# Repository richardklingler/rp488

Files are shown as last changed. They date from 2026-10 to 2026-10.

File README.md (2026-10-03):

# RP488 USB-GPIB Adapter

This project is an RP2350-based USB GPIB adapter.

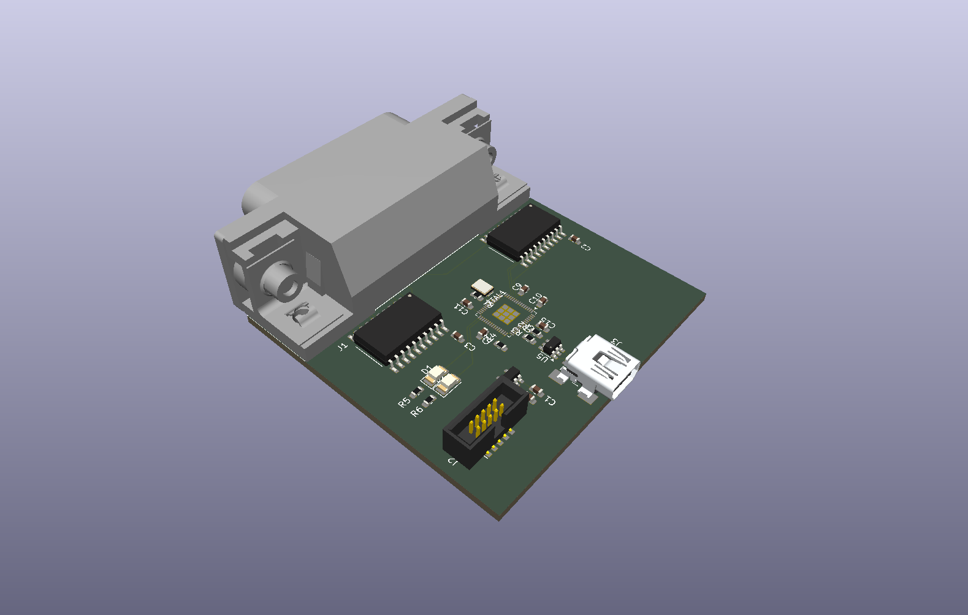
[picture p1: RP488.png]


## USB identifiers

- Vendor ID: `0x1209`
- Product ID: `0x5305`

## Hardware target

- Raspberry Pi Pico 2 W, RP2354
- SN75160B data transceiver
- SN75161B control transceiver
- GPIB bus interface using negative-true logic

## Test

The design was tested with a Raspberry Pi Pico 2 W board and an attached Yokogawa DL1540C 4-channel scope.
I was able to control the scope and download a binary screenshot as TIFF on macOS 27 with a simple Python script located in folder "test".

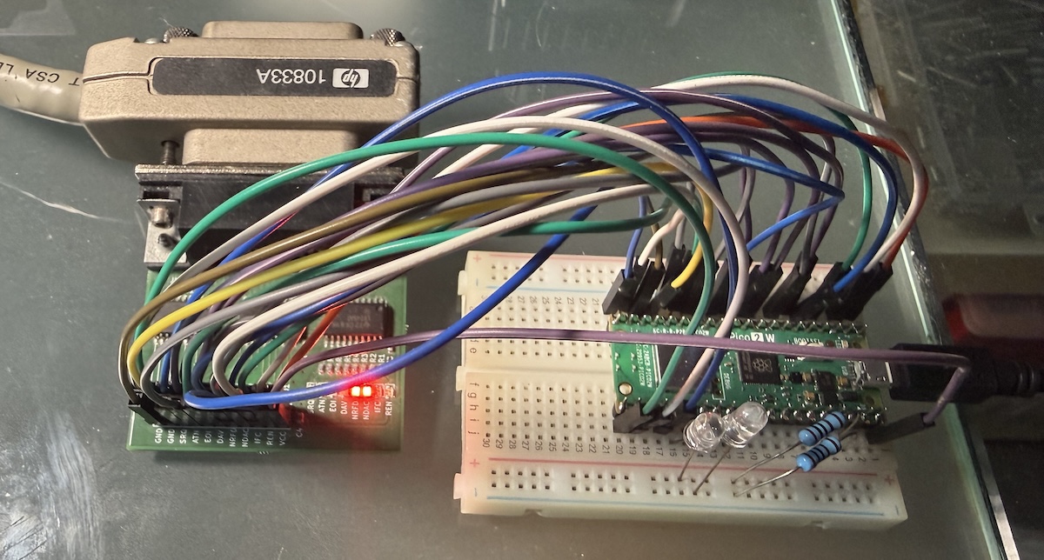
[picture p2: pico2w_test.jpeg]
Test setup


Waveform screenshot taken via binary GPIB transfer:

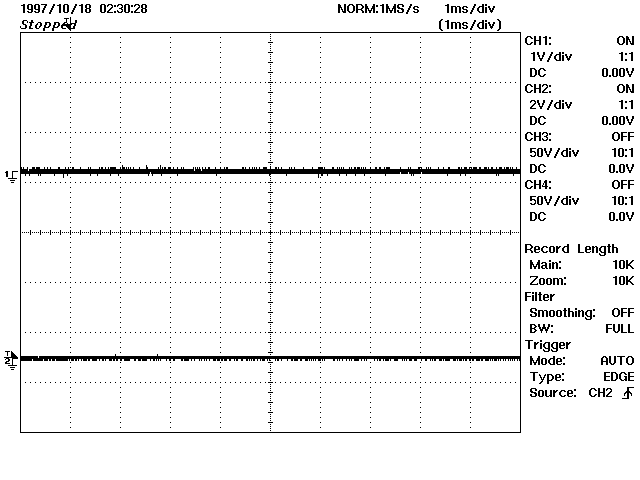
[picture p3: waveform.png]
Waveform Capture


## Hardware

The firmware was tested with the Raspberry Pico 2 W development board and an external GPIB transceiver board.
Firmware should work with all RP2350 variants, including the new RP2354 with built-in 2MB flash.

Hardware design is of course made with KiCAD and is curretnly in the works.

You find the hardware related files in the "Hardware" folder.

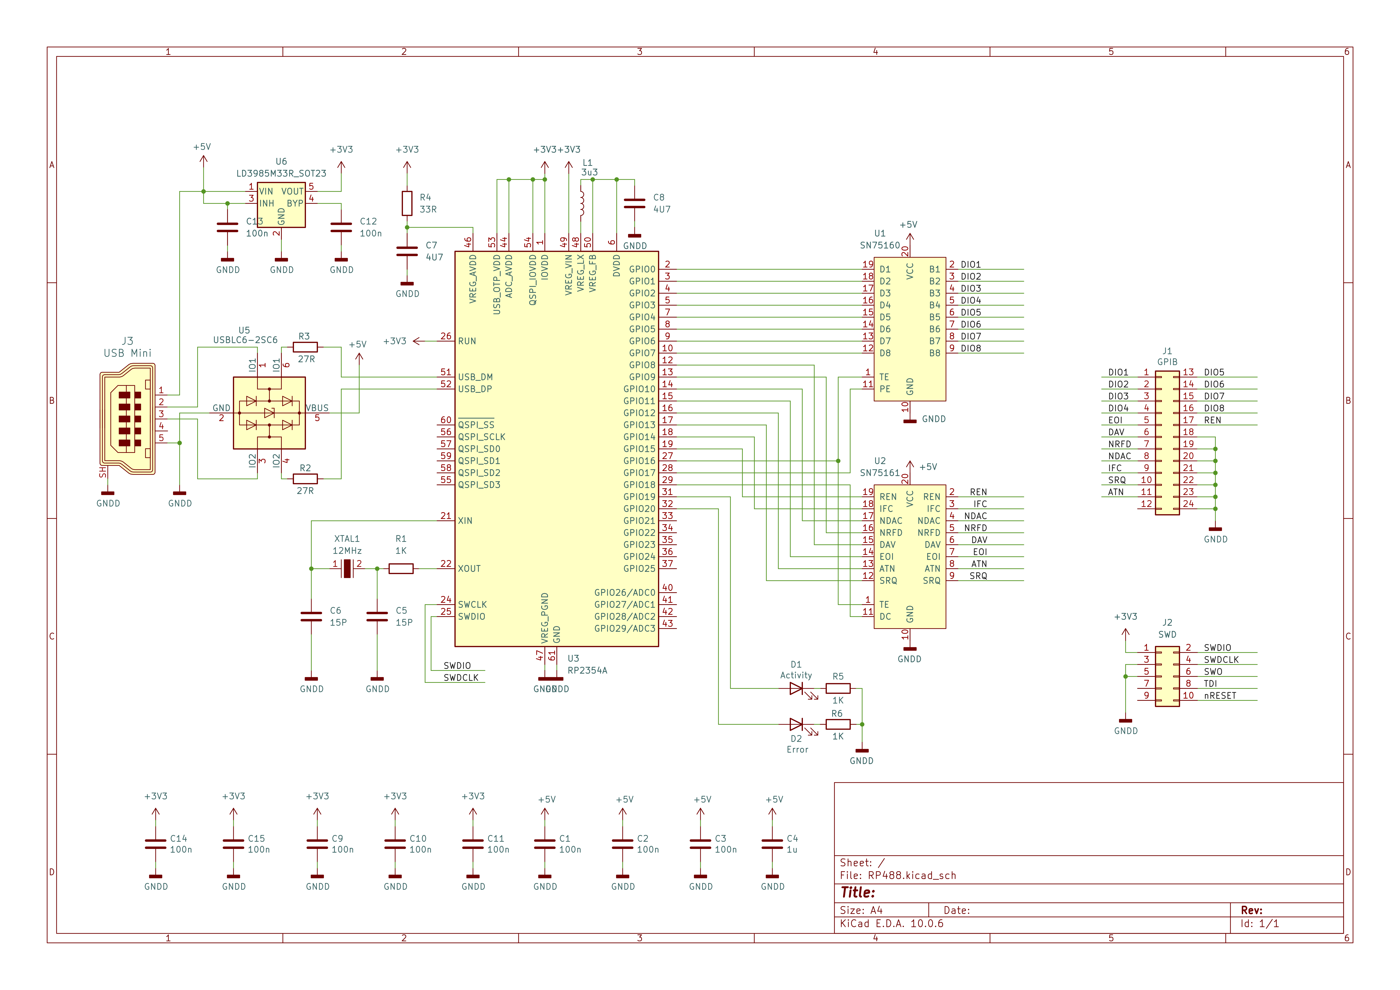
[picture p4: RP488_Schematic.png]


## Firmware goals

- CDC ACM serial interface on USB
- Prologix-compatible ASCII command set
- Framed binary mode for large block transfers
- Controller-in-charge operation
- Serial poll and SRQ support
- Bus-safe handshake sequencing and timeout handling

## Build notes

Use the Pico SDK and configure `PICO_SDK_PATH` before generating the build files:

```bash
export PICO_SDK_PATH=/path/to/pico-sdk
cmake -S . -B build
cmake --build build
```

The generated binary is intended for the Pico 2 W with the GPIB interface board described in the implementation guide.

## License

Original hardware design files use CERN-OHL-S-2.0; firmware and software use
MIT. See [LICENSE.md](LICENSE.md) for scope details and links to the license
texts. Third-party materials retain their own licenses.

## Binary block transfers

The firmware supports streaming IEEE definite-length blocks over the CDC
serial connection without buffering the full payload in Pico RAM:

- Send the instrument's block-data query as a normal text line.
- Send `++bin read <maxlen>` to read the response. The adapter forwards the
	`#<digits><length>` header followed by exactly that many payload bytes. The
	limit is capped at 16 MiB.
- For a binary write, send `++bin write <len>` as a line, followed by exactly
	`<len>` raw bytes. The final byte is sent with EOI; no EOS characters are
	appended.

These transfers are binary, not terminal text. Use a serial client that can
read and write exact byte counts; do not rely on a terminal application's
line-oriented display for waveform data.

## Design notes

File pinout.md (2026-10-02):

# BusLink Wiring Pinout

Proposed wiring for a Raspberry Pi Pico 2 W connected to the SN75160B data
transceiver and SN75161B management transceiver. The GPIO assignments match
the firmware definitions and the pin map in `gpib-usb-adapter.md`.

## GPIO and Pico Header Map

| Signal | Pico GPIO | Pico 2 W header pin | Direction / notes |
|---|---:|---:|---|
| DIO1 | GPIO0 | 1 | Bidirectional through SN75160B |
| DIO2 | GPIO1 | 2 | Bidirectional through SN75160B |
| DIO3 | GPIO2 | 4 | Bidirectional through SN75160B |
| DIO4 | GPIO3 | 5 | Bidirectional through SN75160B |
| DIO5 | GPIO4 | 6 | Bidirectional through SN75160B |
| DIO6 | GPIO5 | 7 | Bidirectional through SN75160B |
| DIO7 | GPIO6 | 9 | Bidirectional through SN75160B |
| DIO8 | GPIO7 | 10 | Bidirectional through SN75160B |
| DAV | GPIO8 | 11 | Bidirectional handshake line |
| NRFD | GPIO9 | 12 | Bidirectional handshake line |
| NDAC | GPIO10 | 14 | Bidirectional handshake line |
| EOI | GPIO11 | 15 | Bidirectional; direction depends on bus role and ATN |
| ATN | GPIO12 | 16 | Controller output |
| SRQ | GPIO13 | 17 | Controller input |
| IFC | GPIO14 | 19 | Controller output |
| REN | GPIO15 | 20 | Controller output |
| TE | GPIO16 | 21 | SN75160B/SN75161B transceiver control output |
| PE | GPIO17 | 22 | SN75160B transceiver control output |
| DC | GPIO18 | 24 | SN75161B transceiver control output |
| Activity LED | GPIO19 | 25 | Output; active high through a series resistor |
| Error LED | GPIO20 | 26 | Output; active high through a series resistor; latches until a successful GPIB operation |

GPIO21-22 remain unused by this pinout and are available for later expansion.

## Power and Ground

| Pico header pin | Connect to |
|---:|---|
| 40 (VBUS) | Interface board +5 V rail |
| 3 (GND) and 8 (GND) | Interface board ground; use at least two ground wires |

Keep the Pico and transceiver board grounds common. The design takes +5 V from
Pico VBUS so the transceivers cannot remain powered while the RP2350 is off.
Do not connect the GPIB bus directly to Pico GPIO; all bus signals must pass
through the specified transceivers. If the interface board is powered
separately, follow the series-resistor and power-sequencing precautions in the
implementation guide.

## J2 Cable Mapping

Wire J2 by the signal names in the table, not by assuming a ribbon-cable order.
The implementation guide does not establish J2's physical pin numbering, so
verify every J2 pin against the board schematic and continuity-test the cable
before applying power. Keep DIO1-DIO8 contiguous and DAV/NRFD/NDAC contiguous
where possible.

## Logic and Direction Notes

- GPIB is negative-true: an asserted signal is low on the MCU side of the
  non-inverting transceivers.
- The DIO GPIO order is DIO1 through DIO8 on GPIO0 through GPIO7. Firmware must
  complement data bytes when transmitting and receiving.
- DAV, NRFD, NDAC, and EOI change direction with the talker/listener role. The
  firmware must set GPIO directions and transceiver controls for the active
  role before bus transfers.
- For normal operation, the design guide specifies DC low, PE high, and TE
  selected for talker or listener operation. See the transceiver truth tables
  in `gpib-usb-adapter.md` before wiring or testing the control logic.
- Connect each LED from its GPIO through its own series resistor (about 1 kΩ)
  to ground. Do not connect indicator LEDs directly to GPIB bus lines.

This is the proposed signal assignment, not a verified J2-to-Pico cable
schedule. Confirm the J2 connections against the actual schematic before
powering the adapter.

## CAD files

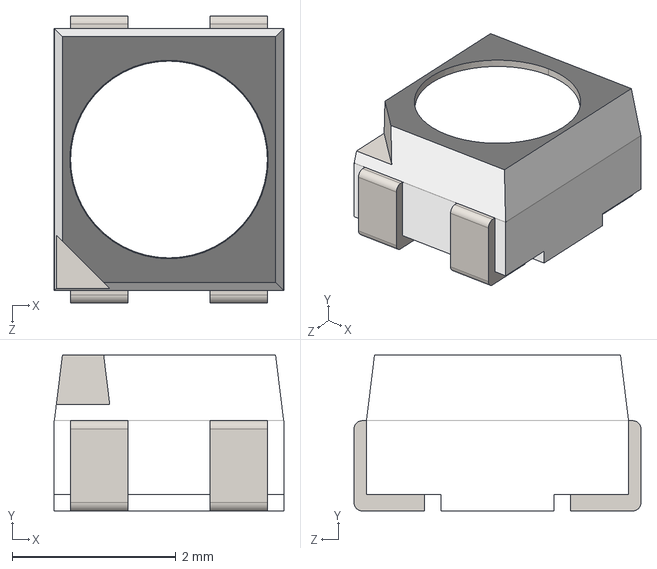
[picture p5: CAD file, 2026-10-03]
Hardware/3d/ASMB-MTB0-0A3A2.STEP
2.80 x 1.90 x 3.50 mm

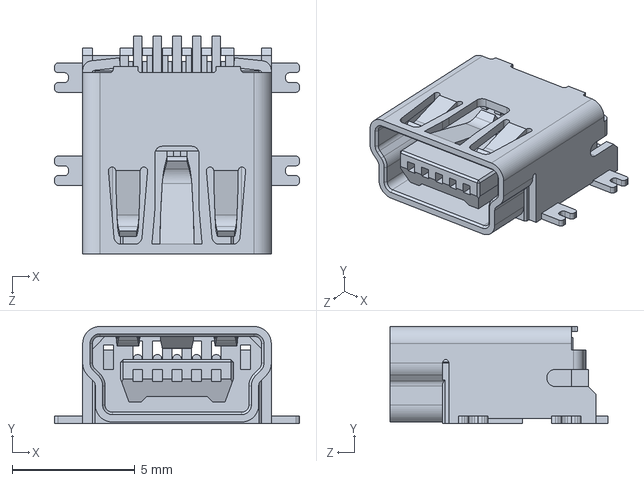
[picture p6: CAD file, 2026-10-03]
Hardware/3d/USB_Mini_B_SMD_buchse.step
10.0 x 3.96 x 8.90 mm

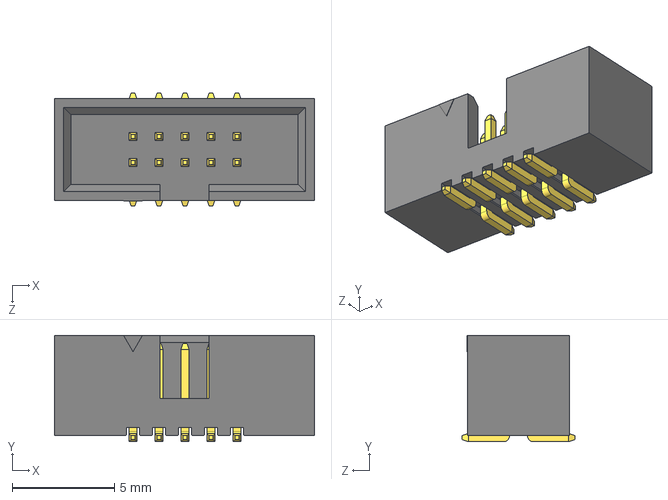
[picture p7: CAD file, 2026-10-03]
Hardware/3d/3220-10-0300-00 3D.step
12.7 x 5.20 x 5.50 mm
801-2195SM-10
802-2195SM x 10

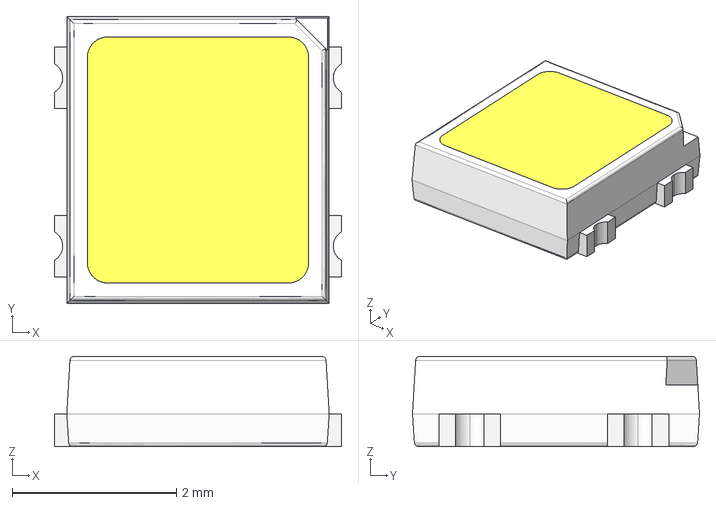
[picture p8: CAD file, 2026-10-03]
Hardware/3d/PLCC4.stp
3.50 x 3.50 x 1.10 mm

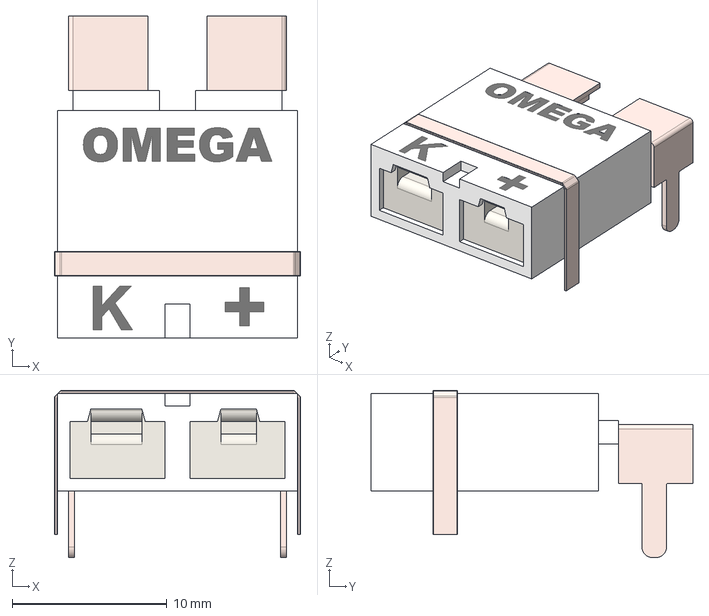
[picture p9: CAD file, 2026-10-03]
Hardware/3d/PCC-SMP-K.step
15.9 x 20.8 x 10.8 mm

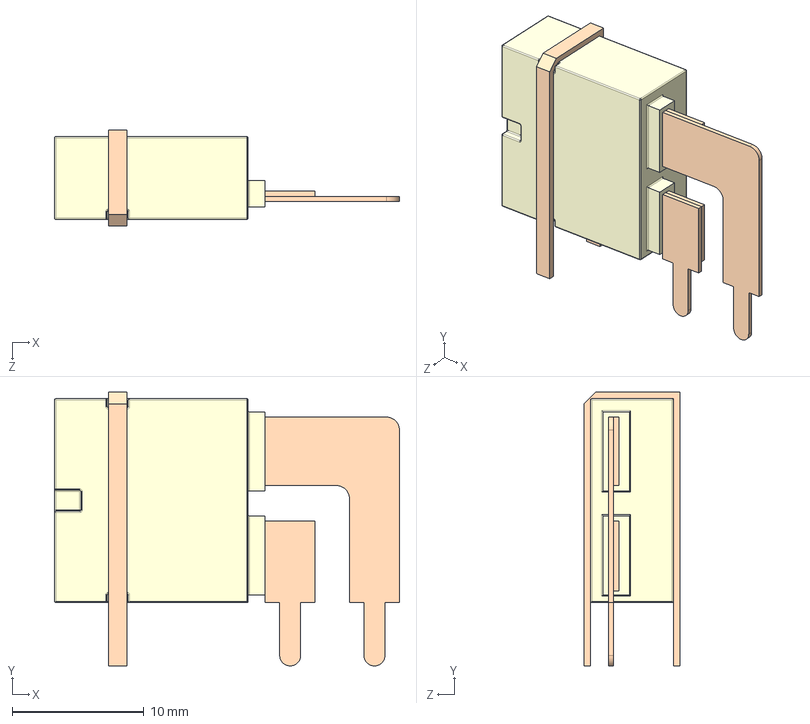
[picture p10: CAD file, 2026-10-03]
Hardware/3d/PCC-SMP-V-K--3DModel-STEP-56544.STEP
26.2 x 20.8 x 7.30 mm

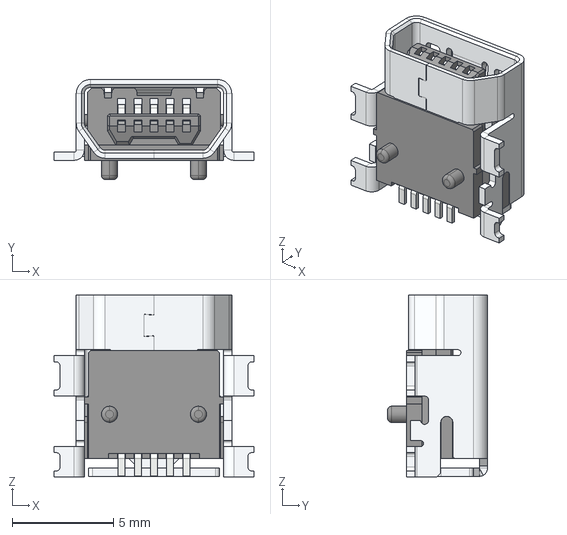
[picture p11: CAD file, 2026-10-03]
Hardware/3d/MOLEX_0678038020.step
9.90 x 4.95 x 9.00 mm

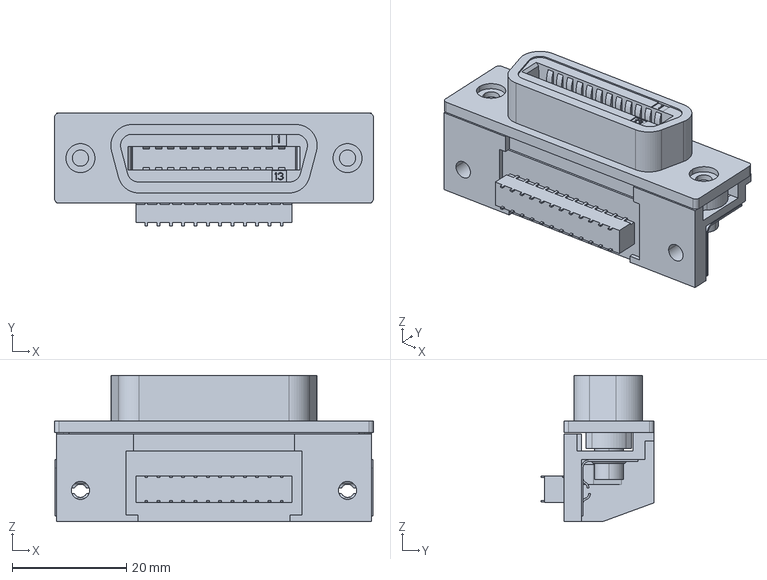
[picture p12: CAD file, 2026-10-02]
Hardware/3d/c-5553811-1-o-3d.stp
55.9 x 19.7 x 25.7 mm

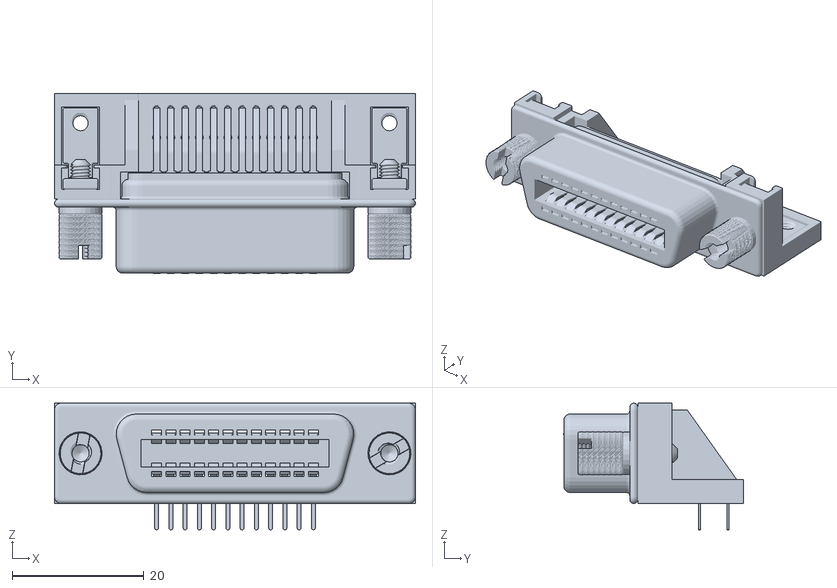
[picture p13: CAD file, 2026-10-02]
Hardware/3d/gpib.stl
54.7 x 27.3 x 19.2

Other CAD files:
Hardware/3d/GPIB2.obj
Hardware/3d/GPIB.obj

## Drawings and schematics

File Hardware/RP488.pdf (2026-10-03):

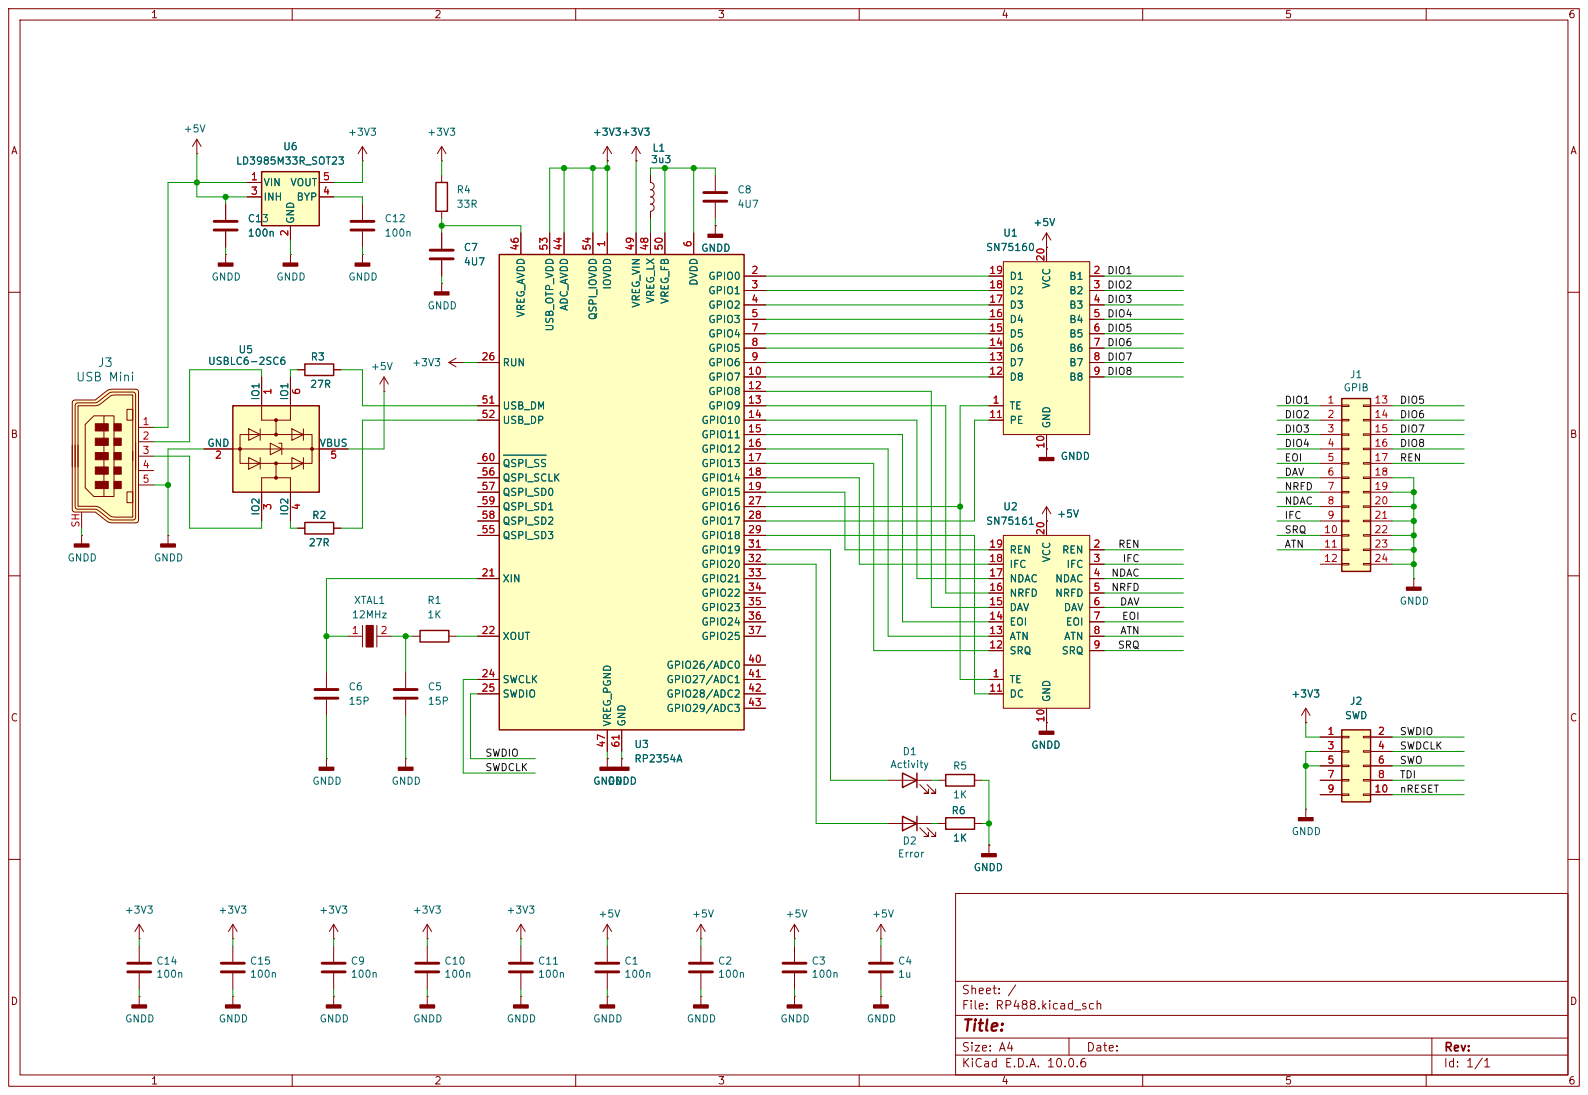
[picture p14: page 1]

Size: A4 | Rev:
KiCad E.D.A. 10.0.6 | Id: 1/1

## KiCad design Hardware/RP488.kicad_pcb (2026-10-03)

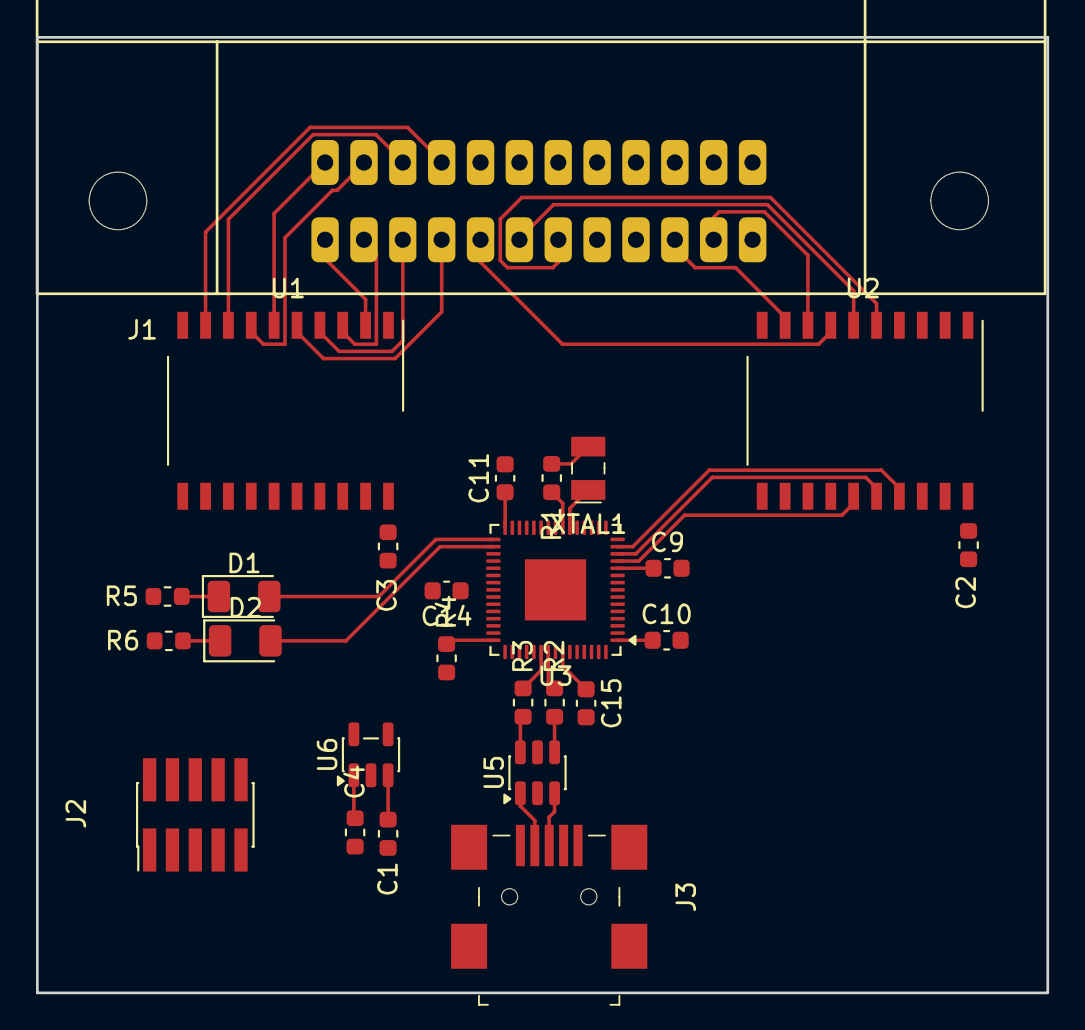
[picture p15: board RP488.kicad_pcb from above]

Board: 2 copper layers, 56.1 x 53.1 mm, 26 parts (0 on the bottom side), 55 nets.

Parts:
C1, C2, C3, C9, C10, C11, C14, C15: 100n; C_0603_1608Metric
C4: 1u; C_0603_1608Metric
D1, D2: LED; LED_1206_3216Metric
J1: GPIB; 5553811
J2: SWD; PinHeader_2x05_P1.27mm_Vertical_SMD
J3: USB Mini; USB_Mini_B_Female_690-005-299-043
R1, R5, R6: 1K; R_0603_1608Metric
R2, R3: 27R; R_0603_1608Metric
R4: 33R; R_0603_1608Metric
U1: SN75160; SO-20_12.8x7.5mm_P1.27mm
U2: SN75161; SO-20_12.8x7.5mm_P1.27mm
U3: RP2354A; QFN-60-1EP_7x7mm_P0.4mm_EP3.4x3.4mm
U5: USBLC6-2SC6; SOT-23-6
U6: LD3985M33R_SOT23; SOT-23-5
XTAL1: 12MHz; SMD-2_3.2x1.5mm

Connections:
+3V3: C9.1, C10.1, C11.1, C14.1, C15.1, J2.1, R4.2, U3.1 (IOVDD), U3.11 (IOVDD), U3.20 (IOVDD), U3.26 (RUN), U3.30 (IOVDD), U3.38 (IOVDD), U3.44 (ADC_AVDD), U3.45 (IOVDD), U3.49 (VREG_VIN), U3.53 (USB_OTP_VDD), U3.54 (QSPI_IOVDD), U6.5 (VOUT)
+5V: C1.1, C2.1, C3.1, C4.1, J3.1, U1.20 (VCC), U2.20 (VCC), U5.5 (VBUS), U6.1 (VIN), U6.3 (INH)
/ATN: J1.11, U2.8 (ATN)
/DAV: J1.6, U2.6 (DAV)
/DIO1: J1.1, U1.2 (B1)
/DIO2: J1.2, U1.3 (B2)
/DIO3: J1.3, U1.4 (B3)
/DIO4: J1.4, U1.5 (B4)
/DIO5: J1.13, U1.6 (B5)
/DIO6: J1.14, U1.7 (B6)
/DIO7: J1.15, U1.8 (B7)
/DIO8: J1.16, U1.9 (B8)
/EOI: J1.5, U2.7 (EOI)
/IFC: J1.9, U2.3 (IFC)
/NDAC: J1.8, U2.4 (NDAC)
/NRFD: J1.7, U2.5 (NRFD)
/REN: J1.17, U2.2 (REN)
/SRQ: J1.10, U2.9 (SRQ)
/SWDCLK: J2.4, U3.24 (SWCLK)
/SWDIO: J2.2, U3.25 (SWDIO)
GNDD: C1.2, C2.2, C3.2, C4.2, C9.2, C10.2, C11.2, C14.2, C15.2, J1.18, J1.19, J1.20, J1.21, J1.22, J1.23, J1.24, J2.3, J2.5, J3.5, J3.SH, R5.2, R6.2, U1.10 (GND), U2.10 (GND), U3.47 (VREG_PGND), U3.61 (GND), U5.2 (GND), U6.2 (GND)
unnamed: R1.1, XTAL1.2
unnamed: D1.2 (A), U3.31 (GPIO19)
unnamed: D1.1 (K), R5.1
unnamed: D2.2 (A), U3.32 (GPIO20)
unnamed: D2.1 (K), R6.1
unnamed: J3.2, U5.1 (IO1)
unnamed: J3.3, U5.3 (IO2)
unnamed: R2.1, U5.4 (IO2)
unnamed: R3.1, U5.6 (IO1)
unnamed: U1.19 (D1), U3.2 (GPIO0)
unnamed: U1.18 (D2), U3.3 (GPIO1)
unnamed: U1.17 (D3), U3.4 (GPIO2)
unnamed: U1.16 (D4), U3.5 (GPIO3)
unnamed: U1.15 (D5), U3.7 (GPIO4)
unnamed: U1.14 (D6), U3.8 (GPIO5)
unnamed: U1.13 (D7), U3.9 (GPIO6)
unnamed: U1.12 (D8), U3.10 (GPIO7)
unnamed: U1.11 (PE), U3.28 (GPIO17)
unnamed: U1.1 (TE), U2.1 (TE), U3.27 (GPIO16)
unnamed: U2.11 (DC), U3.29 (GPIO18)
unnamed: U2.15 (DAV), U3.12 (GPIO8)
unnamed: U2.16 (NRFD), U3.13 (GPIO9)
unnamed: U2.17 (NDAC), U3.14 (GPIO10)
unnamed: U2.14 (EOI), U3.15 (GPIO11)
unnamed: U2.13 (ATN), U3.16 (GPIO12)
unnamed: U2.12 (SRQ), U3.17 (GPIO13)
unnamed: U2.18 (IFC), U3.18 (GPIO14)
unnamed: U2.19 (REN), U3.19 (GPIO15)
unnamed: R3.2, U3.51 (USB_DM)
unnamed: R2.2, U3.52 (USB_DP)
unnamed: R4.1, U3.46 (VREG_AVDD)
unnamed: U3.6 (DVDD), U3.23 (DVDD), U3.39 (DVDD), U3.50 (VREG_FB)
unnamed: U3.21 (XIN), XTAL1.1
unnamed: R1.2, U3.22 (XOUT)

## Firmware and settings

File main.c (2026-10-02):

#include <ctype.h>
#include <stdbool.h>
#include <stdint.h>
#include <stdio.h>
#include <stdlib.h>
#include <string.h>

#include "pico/stdio_usb.h"
#include "pico/stdlib.h"

#define GPIB_DIO_BASE 0u
#define GPIB_DIO_MASK 0xFFu
#define GPIB_DAV_PIN 8u
#define GPIB_NRFD_PIN 9u
#define GPIB_NDAC_PIN 10u
#define GPIB_EOI_PIN 11u
#define GPIB_ATN_PIN 12u
#define GPIB_SRQ_PIN 13u
#define GPIB_IFC_PIN 14u
#define GPIB_REN_PIN 15u
#define GPIB_TE_PIN 16u
#define GPIB_PE_PIN 17u
#define GPIB_DC_PIN 18u
#define LED_ACTIVITY_PIN 19u
#define LED_ERROR_PIN 20u
#define LED_ACTIVITY_PULSE_US 100000u

#define GPIB_CTRL_MASK ((1u << GPIB_DAV_PIN) | (1u << GPIB_NRFD_PIN) | \
                        (1u << GPIB_NDAC_PIN) | (1u << GPIB_EOI_PIN) | \
                        (1u << GPIB_ATN_PIN) | (1u << GPIB_SRQ_PIN) | \
                        (1u << GPIB_IFC_PIN) | (1u << GPIB_REN_PIN) | \
                        (1u << GPIB_TE_PIN) | (1u << GPIB_PE_PIN) | \
                        (1u << GPIB_DC_PIN))
#define GPIB_TIMEOUT_MS 3000u
#define USB_LINE_SIZE 256u
#define GPIB_DEFAULT_ADDRESS 8u
#define GPIB_MAX_BINARY_LENGTH (16u * 1024u * 1024u)

static uint8_t gpib_address = GPIB_DEFAULT_ADDRESS;
static uint8_t gpib_eos = 0u;
static bool gpib_eoi_enabled = true;
static bool gpib_auto_read = false;
static uint32_t gpib_read_timeout_ms = GPIB_TIMEOUT_MS;
static const char *gpib_phase = "idle";
static const char *gpib_timeout_reason = "none";
static uint32_t gpib_timeout_gpio_state;
static uint64_t activity_led_deadline_us;

static void activity_led_pulse(void)
{
    activity_led_deadline_us = time_us_64() + LED_ACTIVITY_PULSE_US;
    gpio_put(LED_ACTIVITY_PIN, 1u);
}

static void error_led_set(bool on)
{
    gpio_put(LED_ERROR_PIN, on ? 1u : 0u);
}

static void report_adapter_error(const char *message)
{
    error_led_set(true);
    puts(message);
}

static void gpib_note_timeout(const char *reason)
{
    gpib_timeout_reason = reason;
    gpib_timeout_gpio_state = gpio_get_all();
    error_led_set(true);
}

static void gpib_output(uint pin, bool high)
{
    gpio_put(pin, high ? 1u : 0u);
    gpio_set_dir(pin, GPIO_OUT);
}

static bool gpib_wait_level(uint pin, bool high, uint32_t timeout_ms)
{
    uint64_t deadline = time_us_64() + (uint64_t)timeout_ms * 1000u;
    while ((gpio_get(pin) != 0u) != high) {
        if (time_us_64() >= deadline) {
            return false;
        }
        tight_loop_contents();
    }
    return true;
}

static void gpib_set_talker(void)
{
    gpio_put_masked(GPIB_DIO_MASK, GPIB_DIO_MASK);
    gpio_put(GPIB_DAV_PIN, 1u);
    gpio_put(GPIB_EOI_PIN, 1u);
    gpio_put(GPIB_NRFD_PIN, 0u);
    gpio_put(GPIB_NDAC_PIN, 0u);

    gpio_set_dir(GPIB_NRFD_PIN, GPIO_IN);
    gpio_set_dir(GPIB_NDAC_PIN, GPIO_IN);
    gpio_put(GPIB_TE_PIN, 1u);

    for (uint gpio = GPIB_DIO_BASE; gpio < GPIB_DIO_BASE + 8u; ++gpio) {
        gpio_set_dir(gpio, GPIO_OUT);
    }
    gpio_set_dir(GPIB_DAV_PIN, GPIO_OUT);
    gpio_set_dir(GPIB_EOI_PIN, GPIO_OUT);
}

static void gpib_set_listener(void)
{
    gpio_put(GPIB_DAV_PIN, 1u);
    gpio_put(GPIB_EOI_PIN, 1u);
    gpio_put_masked(GPIB_DIO_MASK, GPIB_DIO_MASK);
    for (uint gpio = GPIB_DIO_BASE; gpio < GPIB_DIO_BASE + 8u; ++gpio) {
        gpio_set_dir(gpio, GPIO_IN);
    }
    gpio_set_dir(GPIB_DAV_PIN, GPIO_IN);
    gpio_set_dir(GPIB_EOI_PIN, GPIO_IN);

    gpib_output(GPIB_NRFD_PIN, false);
    gpib_output(GPIB_NDAC_PIN, false);
    gpio_put(GPIB_TE_PIN, 0u);
}

static void gpib_gpio_init(void)
{
    gpio_init_mask(GPIB_DIO_MASK | GPIB_CTRL_MASK |
                   (1u << LED_ACTIVITY_PIN) | (1u << LED_ERROR_PIN));

    gpib_output(GPIB_DC_PIN, false);
    gpib_output(GPIB_PE_PIN, true);
    gpib_output(GPIB_ATN_PIN, true);
    gpib_output(GPIB_IFC_PIN, true);
    gpib_output(GPIB_REN_PIN, true);
    gpib_output(GPIB_TE_PIN, false);
    gpio_set_dir(GPIB_SRQ_PIN, GPIO_IN);
    gpio_set_dir(LED_ACTIVITY_PIN, GPIO_OUT);
    gpio_put(LED_ACTIVITY_PIN, 0u);
    gpio_set_dir(LED_ERROR_PIN, GPIO_OUT);
    gpio_put(LED_ERROR_PIN, 0u);
    gpio_set_dir(GPIB_DAV_PIN, GPIO_IN);
    gpio_set_dir(GPIB_EOI_PIN, GPIO_IN);
    for (uint gpio = GPIB_DIO_BASE; gpio < GPIB_DIO_BASE + 8u; ++gpio) {
        gpio_set_dir(gpio, GPIO_IN);
    }

    gpib_set_listener();
    gpio_put(GPIB_IFC_PIN, 0u);
    sleep_us(100u);
    gpio_put(GPIB_IFC_PIN, 1u);
}

static bool gpib_write_byte(uint8_t byte, bool eoi)
{
    if (!gpib_wait_level(GPIB_NRFD_PIN, true, GPIB_TIMEOUT_MS)) {
        gpib_note_timeout("NRFD did not release");
        return false;
    }

    gpio_put_masked(GPIB_DIO_MASK, (uint8_t)~byte);
    gpio_put(GPIB_EOI_PIN, eoi ? 0u : 1u);
    busy_wait_us(2u);
    gpio_put(GPIB_DAV_PIN, 0u);

    if (!gpib_wait_level(GPIB_NDAC_PIN, true, GPIB_TIMEOUT_MS)) {
        gpio_put(GPIB_DAV_PIN, 1u);
        gpio_put(GPIB_EOI_PIN, 1u);
        gpib_note_timeout("NDAC did not release after DAV assertion");
        return false;
    }

    gpio_put(GPIB_DAV_PIN, 1u);
    gpio_put(GPIB_EOI_PIN, 1u);
    if (!gpib_wait_level(GPIB_NDAC_PIN, false, GPIB_TIMEOUT_MS)) {
        gpib_note_timeout("NDAC did not assert after DAV release");
        return false;
    }
    activity_led_pulse();
    return true;
}

static bool gpib_read_byte(uint8_t *byte, bool *eoi)
{
    gpio_put(GPIB_NRFD_PIN, 1u);
    if (!gpib_wait_level(GPIB_DAV_PIN, false, gpib_read_timeout_ms)) {
        gpio_put(GPIB_NRFD_PIN, 0u);
        gpib_note_timeout("DAV did not assert while listening");
        return false;
    }

    gpio_put(GPIB_NRFD_PIN, 0u);
    *byte = (uint8_t)~gpio_get_all();
    *eoi = gpio_get(GPIB_EOI_PIN) == 0u;
    gpio_put(GPIB_NDAC_PIN, 1u);

    if (!gpib_wait_level(GPIB_DAV_PIN, true, gpib_read_timeout_ms)) {
        gpio_put(GPIB_NDAC_PIN, 0u);
        gpib_note_timeout("DAV did not release after accepting byte");
        return false;
    }

    gpio_put(GPIB_NDAC_PIN, 0u);
    activity_led_pulse();
    return true;
}

static bool gpib_send_commands(const uint8_t *commands, size_t count)
{
    gpio_put(GPIB_ATN_PIN, 0u);
    gpib_set_talker();
    for (size_t i = 0; i < count; ++i) {
        gpib_phase = "GPIB command bytes";
        if (!gpib_write_byte(commands[i], false)) {
            gpio_put(GPIB_ATN_PIN, 1u);
            gpib_set_listener();
            return false;
        }
    }
    gpio_put(GPIB_ATN_PIN, 1u);
    return true;
}

static bool gpib_address_for_write(void)
{
    const uint8_t commands[] = {0x3Fu, (uint8_t)(0x20u + gpib_address), 0x40u};
    return gpib_send_commands(commands, sizeof(commands));
}

static bool gpib_address_for_read(void)
{
    const uint8_t commands[] = {0x3Fu, (uint8_t)(0x40u + gpib_address), 0x20u};
    if (!gpib_send_commands(commands, sizeof(commands))) {
        return false;
    }
    gpib_set_listener();
    return true;
}

static bool gpib_read_stream(bool stop_on_eoi, int terminator)
{
    if (!gpib_address_for_read()) {
        return false;
    }

    gpib_phase = "instrument response";
    for (;;) {
        uint8_t byte;
        bool eoi;
        if (!gpib_read_byte(&byte, &eoi)) {
            return false;
        }
        putchar_raw(byte);
        if ((stop_on_eoi && eoi) || (!stop_on_eoi && byte == (uint8_t)terminator)) {
            error_led_set(false);
            return true;
        }
    }
}

static bool gpib_binary_write(uint32_t length)
{
    if (!gpib_address_for_write()) {
        return false;
    }

    uint64_t deadline = time_us_64() + (uint64_t)gpib_read_timeout_ms * 1000u;
    gpib_phase = "binary data";
    for (uint32_t i = 0; i < length; ++i) {
        int ch;
        do {
            ch = getchar_timeout_us(10000u);
            if (ch == PICO_ERROR_TIMEOUT && time_us_64() >= deadline) {
                gpib_set_listener();
                return false;
            }
        } while (ch == PICO_ERROR_TIMEOUT);

        if (!gpib_write_byte((uint8_t)ch, i + 1u == length)) {
            gpib_set_listener();
            return false;
        }
    }

    gpib_set_listener();
    error_led_set(false);
    return true;
}

static bool gpib_read_ieee_block(uint32_t maximum_length)
{
    uint8_t header[11];
    uint8_t byte;
    bool eoi;

    if (!gpib_address_for_read()) {
        gpib_set_listener();
        report_adapter_error("ERR: GPIB timeout before IEEE block");
        return false;
    }
    if (!gpib_read_byte(&byte, &eoi)) {
        gpib_set_listener();
        report_adapter_error("ERR: GPIB timeout before IEEE block");
        return false;
    }
    if (byte != '#') {
        gpib_set_listener();
        report_adapter_error("ERR: expected IEEE definite-length block");
        return false;
    }
    header[0] = byte;

    if (!gpib_read_byte(&byte, &eoi)) {
        gpib_set_listener();
        report_adapter_error("ERR: GPIB timeout in IEEE block header");
        return false;
    }
    if (byte < '1' || byte > '9') {
        gpib_set_listener();
        report_adapter_error("ERR: expected IEEE definite-length block");
        return false;
    }
    header[1] = byte;
    uint8_t length_digits = (uint8_t)(byte - '0');
    uint32_t payload_length = 0u;

    for (uint8_t i = 0; i < length_digits; ++i) {
        if (!gpib_read_byte(&byte, &eoi)) {
            gpib_set_listener();
            report_adapter_error("ERR: GPIB timeout in IEEE block length");
            return false;
        }
        if (byte < '0' || byte > '9') {
            gpib_set_listener();
            report_adapter_error("ERR: invalid IEEE block length");
            return false;
        }
        header[2u + i] = byte;
        uint32_t digit = (uint32_t)(byte - '0');
        if (payload_length > (UINT32_MAX - digit) / 10u) {
            gpib_set_listener();
            report_adapter_error("ERR: IEEE block length overflow");
            return false;
        }
        payload_length = payload_length * 10u + digit;
    }

    if (payload_length > maximum_length) {
        gpib_set_listener();
        report_adapter_error("ERR: IEEE block exceeds requested maximum");
        return false;
    }

    for (uint8_t i = 0; i < (uint8_t)(2u + length_digits); ++i) {
        putchar_raw(header[i]);
    }

    for (uint32_t i = 0; i < payload_length; ++i) {
        if (!gpib_read_byte(&byte, &eoi)) {
            gpib_set_listener();
            return false;
        }
        putchar_raw(byte);
    }

    if (!eoi) {
        for (uint8_t trailing = 0; trailing < 8u && !eoi; ++trailing) {
            if (!gpib_read_byte(&byte, &eoi)) {
                gpib_set_listener();
                return false;
            }
        }
        if (!eoi) {
            gpib_set_listener();
            return false;
        }
    }

    gpib_set_listener();
    error_led_set(false);
    return true;
}

static bool gpib_write_text(const char *text)
{
    size_t length = strlen(text);
    size_t eos_length = gpib_eos == 0u ? 2u : (gpib_eos == 3u ? 0u : 1u);
    size_t total = length + eos_length;
    if (total == 0u || !gpib_address_for_write()) {
        gpib_set_listener();
        return total == 0u;
    }

    gpib_phase = "SCPI data";
    for (size_t i = 0; i < total; ++i) {
        uint8_t byte;
        if (i < length) {
            byte = (uint8_t)text[i];
        } else if (gpib_eos == 0u) {
            byte = i == length ? '\r' : '\n';
        } else {
            byte = gpib_eos == 1u ? '\r' : '\n';
        }
        if (!gpib_write_byte(byte, gpib_eoi_enabled && i + 1u == total)) {
            gpib_set_listener();
            return false;
        }
    }

    gpib_set_listener();
    error_led_set(false);
    return true;
}

static bool gpib_serial_poll(uint8_t address, uint8_t *status)
{
    const uint8_t commands[] = {0x3Fu, 0x18u, (uint8_t)(0x40u + address), 0x20u};
    if (!gpib_send_commands(commands, sizeof(commands))) {
        return false;
    }

    gpib_set_listener();
    bool eoi;
    if (!gpib_read_byte(status, &eoi)) {
        return false;
    }

    const uint8_t finish[] = {0x19u, 0x5Fu};
    if (!gpib_send_commands(finish, sizeof(finish))) {
        return false;
    }
    error_led_set(false);
    return true;
}

static bool parse_uint(const char *text, uint32_t maximum, uint32_t *value)
{
    char *end;
    unsigned long parsed = strtoul(text, &end, 10);
    if (text == end || *end != '\0' || parsed > maximum) {
        return false;
    }
    *value = (uint32_t)parsed;
    return true;
}

static void report_bus_error(void)
{
    error_led_set(true);
    printf("ERR: GPIB timeout during %s: %s (GPIO=0x%08lx)\r\n",
           gpib_phase, gpib_timeout_reason,
           (unsigned long)gpib_timeout_gpio_state);
    gpib_set_listener();
}

static void handle_adapter_command(char *line)
{
    char *command = strtok(line, " \t");
    char *argument = strtok(NULL, " \t");
    uint32_t value;

    if (command == NULL) {
        return;
    }
    if (strcmp(command, "++ver") == 0) {
        puts("BusLink RP2350 GPIB adapter 0.1");
    } else if (strcmp(command, "++addr") == 0) {
        if (argument == NULL) {
            printf("%u\r\n", gpib_address);
        } else if (parse_uint(argument, 30u, &value)) {
            gpib_address = (uint8_t)value;
        } else {
            report_adapter_error("ERR: address must be 0-30");
        }
    } else if (strcmp(command, "++auto") == 0) {
        if (argument == NULL) {
            printf("%u\r\n", gpib_auto_read ? 1u : 0u);
        } else if (parse_uint(argument, 1u, &value)) {
            gpib_auto_read = value != 0u;
        } else {
            report_adapter_error("ERR: auto must be 0 or 1");
        }
    } else if (strcmp(command, "++eoi") == 0) {
        if (argument == NULL) {
            printf("%u\r\n", gpib_eoi_enabled ? 1u : 0u);
        } else if (parse_uint(argument, 1u, &value)) {
            gpib_eoi_enabled = value != 0u;
        } else {
            report_adapter_error("ERR: eoi must be 0 or 1");
        }
    } else if (strcmp(command, "++eos") == 0) {
        if (argument == NULL) {
            printf("%u\r\n", gpib_eos);
        } else if (parse_uint(argument, 3u, &value)) {
            gpib_eos = (uint8_t)value;
        } else {
            report_adapter_error("ERR: eos must be 0-3");
        }
    } else if (strcmp(command, "++read_tmo_ms") == 0) {
        if (argument == NULL) {
            printf("%lu\r\n", (unsigned long)gpib_read_timeout_ms);
        } else if (parse_uint(argument, 60000u, &value) && value > 0u) {
            gpib_read_timeout_ms = value;
        } else {
            report_adapter_error("ERR: timeout must be 1-60000 ms");
        }
    } else if (strcmp(command, "++ifc") == 0) {
        gpio_put(GPIB_IFC_PIN, 0u);
        sleep_us(100u);
        gpio_put(GPIB_IFC_PIN, 1u);
    } else if (strcmp(command, "++srq") == 0) {
        printf("%u\r\n", gpio_get(GPIB_SRQ_PIN) == 0u ? 1u : 0u);
    } else if (strcmp(command, "++read") == 0) {
        bool stop_on_eoi = argument == NULL || strcmp(argument, "eoi") == 0;
        int terminator = argument == NULL ? '\n' : (unsigned char)argument[0];
        if (!gpib_read_stream(stop_on_eoi, terminator)) {
            report_bus_error();
        }
    } else if (strcmp(command, "++bin") == 0) {
        char *operation = argument;
        char *length_argument = strtok(NULL, " \t");
        if (operation == NULL || length_argument == NULL ||
            !parse_uint(length_argument, GPIB_MAX_BINARY_LENGTH, &value)) {
            report_adapter_error("ERR: use ++bin read <maxlen> or ++bin write <len>");
        } else if (strcmp(operation, "write") == 0) {
            if (!gpib_binary_write(value)) {
                report_bus_error();
            }
        } else if (strcmp(operation, "read") == 0) {
            (void)gpib_read_ieee_block(value);
        } else {
            report_adapter_error("ERR: use ++bin read <maxlen> or ++bin write <len>");
        }
    } else if (strcmp(command, "++spoll") == 0) {
        uint32_t address = gpib_address;
        uint8_t status;
        if (argument != NULL && !parse_uint(argument, 30u, &address)) {
            report_adapter_error("ERR: address must be 0-30");
        } else if (!gpib_serial_poll((uint8_t)address, &status)) {
            report_bus_error();
        } else {
            printf("%u\r\n", status);
        }
    } else if (strcmp(command, "++clr") == 0 || strcmp(command, "++loc") == 0) {
        uint8_t addressed_command = strcmp(command, "++clr") == 0 ? 0x04u : 0x01u;
        const uint8_t commands[] = {0x3Fu, (uint8_t)(0x20u + gpib_address), addressed_command};
        if (!gpib_send_commands(commands, sizeof(commands))) {
            report_bus_error();
        } else {
            gpib_set_listener();
        }
    } else if (strcmp(command, "++llo") == 0) {
        const uint8_t commands[] = {0x11u};
        if (!gpib_send_commands(commands, sizeof(commands))) {
            report_bus_error();
        } else {
            gpib_set_listener();
        }
    } else if (strcmp(command, "++mode") == 0) {
        if (argument == NULL || strcmp(argument, "1") == 0) {
            puts("1");
        } else {
            report_adapter_error("ERR: controller mode only");
        }
    } else {
        report_adapter_error("ERR: unsupported command");
    }
}

static void handle_usb_line(char *line)
{
    while (*line != '\0' && isspace((unsigned char)*line)) {
        ++line;
    }
    size_t length = strlen(line);
    while (length > 0u && isspace((unsigned char)line[length - 1u])) {
        line[--length] = '\0';
    }
    if (length == 0u) {
        return;
    }

    if (strncmp(line, "++", 2u) == 0) {
        handle_adapter_command(line);
    } else if (!gpib_write_text(line)) {
        report_bus_error();
    } else if (gpib_auto_read && strchr(line, '?') != NULL &&
               !gpib_read_stream(true, '\n')) {
        report_bus_error();
    }
}

int main(void)
{
    char line[USB_LINE_SIZE];
    size_t line_length = 0u;
    bool line_overflow = false;

    stdio_init_all();
    gpib_gpio_init();

    while (true) {
        if (activity_led_deadline_us != 0u &&
            time_us_64() >= activity_led_deadline_us) {
            gpio_put(LED_ACTIVITY_PIN, 0u);
            activity_led_deadline_us = 0u;
        }

        int ch = getchar_timeout_us(0u);
        if (ch == PICO_ERROR_TIMEOUT) {
            tight_loop_contents();
            continue;
        }
        if (ch == '\r' || ch == '\n') {
            if (line_length > 0u && !line_overflow) {
                line[line_length] = '\0';
                handle_usb_line(line);
            } else if (line_overflow) {
                report_adapter_error("ERR: command too long");
            }
            line_length = 0u;
            line_overflow = false;
        } else if (!line_overflow) {
            if (line_length + 1u < sizeof(line)) {
                line[line_length++] = (char)ch;
            } else {
                line_overflow = true;
            }
        }
    }
}

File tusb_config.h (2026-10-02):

#ifndef _PICO_STDIO_USB_TUSB_CONFIG_H
#define _PICO_STDIO_USB_TUSB_CONFIG_H

#include "pico/stdio_usb.h"

#if !defined(LIB_TINYUSB_HOST) && !defined(LIB_TINYUSB_DEVICE)
#define CFG_TUSB_RHPORT0_MODE   (OPT_MODE_DEVICE)

#define CFG_TUD_CDC             (1)

#ifndef CFG_TUD_CDC_RX_BUFSIZE
#define CFG_TUD_CDC_RX_BUFSIZE   (TUD_OPT_HIGH_SPEED ? 512 : 64)
#endif
#ifndef CFG_TUD_CDC_TX_BUFSIZE
#define CFG_TUD_CDC_TX_BUFSIZE   (TUD_OPT_HIGH_SPEED ? 512 : 64)
#endif

#ifndef CFG_TUD_CDC_EP_BUFSIZE
#define CFG_TUD_CDC_EP_BUFSIZE   (TUD_OPT_HIGH_SPEED ? 512 : 64)
#endif

#define CFG_TUD_VENDOR            (0)
#endif

#endif

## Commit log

2026-10-02 Added KiCAD project
    [GPIB.obj, GPIB2.obj, RP488.kicad_pcb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]
2026-10-02 Added python example and LED outputs for activity/error
    [gpib.py, main.c]
2026-10-02 Changed design to RP2354
    [RP488.kicad_sch]
2026-10-02 SWD connector and schematic changes
    [RP488.kicad_pcb, RP488.kicad_sch]
2026-10-02 Switch to RP2354
    [RP488.kicad_pcb, RP488.kicad_sch]
2026-10-03 Renamed directory, added PNG of schematic and PCB 3d view
    [3220-10-0300-00 3D.step, ASMB-MTB0-0A3A2.STEP, GPIB.obj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]
